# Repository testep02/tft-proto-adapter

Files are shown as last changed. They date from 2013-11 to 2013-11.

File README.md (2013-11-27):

TFT-Proto Adapters
=================================================================================
The files in this repository are schematics and boards for use in Eagle that provide an easy connection for the TFT-Proto from MikroE to the STM32F4 Discovery. There are 3 different variations of the board in this repository. All of these designs have been verified to work. They can easily be printed through OshPark.

Features
---------------------------------------------------------------------------------
-  TFT backlight connected to a pin to allow PWM control
-  Backlight powered from 5V instead of 3.3V to allow for brighter viewing
-  Backlight controlled through a transistor to prevent driving the LEDs directly from a pin
-  Reset pin also routed through a transistor and connected to a pin for software control

Variations
---------------------------------------------------------------------------------
-  16-bit FSMC Portrait
	-  This version of the board mounts the TFT in portrait mode
	-  The connection to the STM32F4 Discovery is 16-bit parallel and uses FSMC.
-  16-Bit FSMC Landscape
	-  Same as the above variation, except with this one the board is laid out so that the screen is in landscape configuration. This is the variatioon I use.
-  16-bit GPIO
	-  Uses entire GPIOE port for data lines
	-  Uses sme pins on the GPIOB port for control
	-  IM[3:0] are connected to header pins to allow configuration between 16-bit and 8-bit
	-  Is not connected to the FSMC pins, so bit-banging is required

Code Examples
---------------------------------------------------------------------------------
Examples of driving the TFT-Proto can be found in my other repository. The drivers include all init code and basic drawing functions.

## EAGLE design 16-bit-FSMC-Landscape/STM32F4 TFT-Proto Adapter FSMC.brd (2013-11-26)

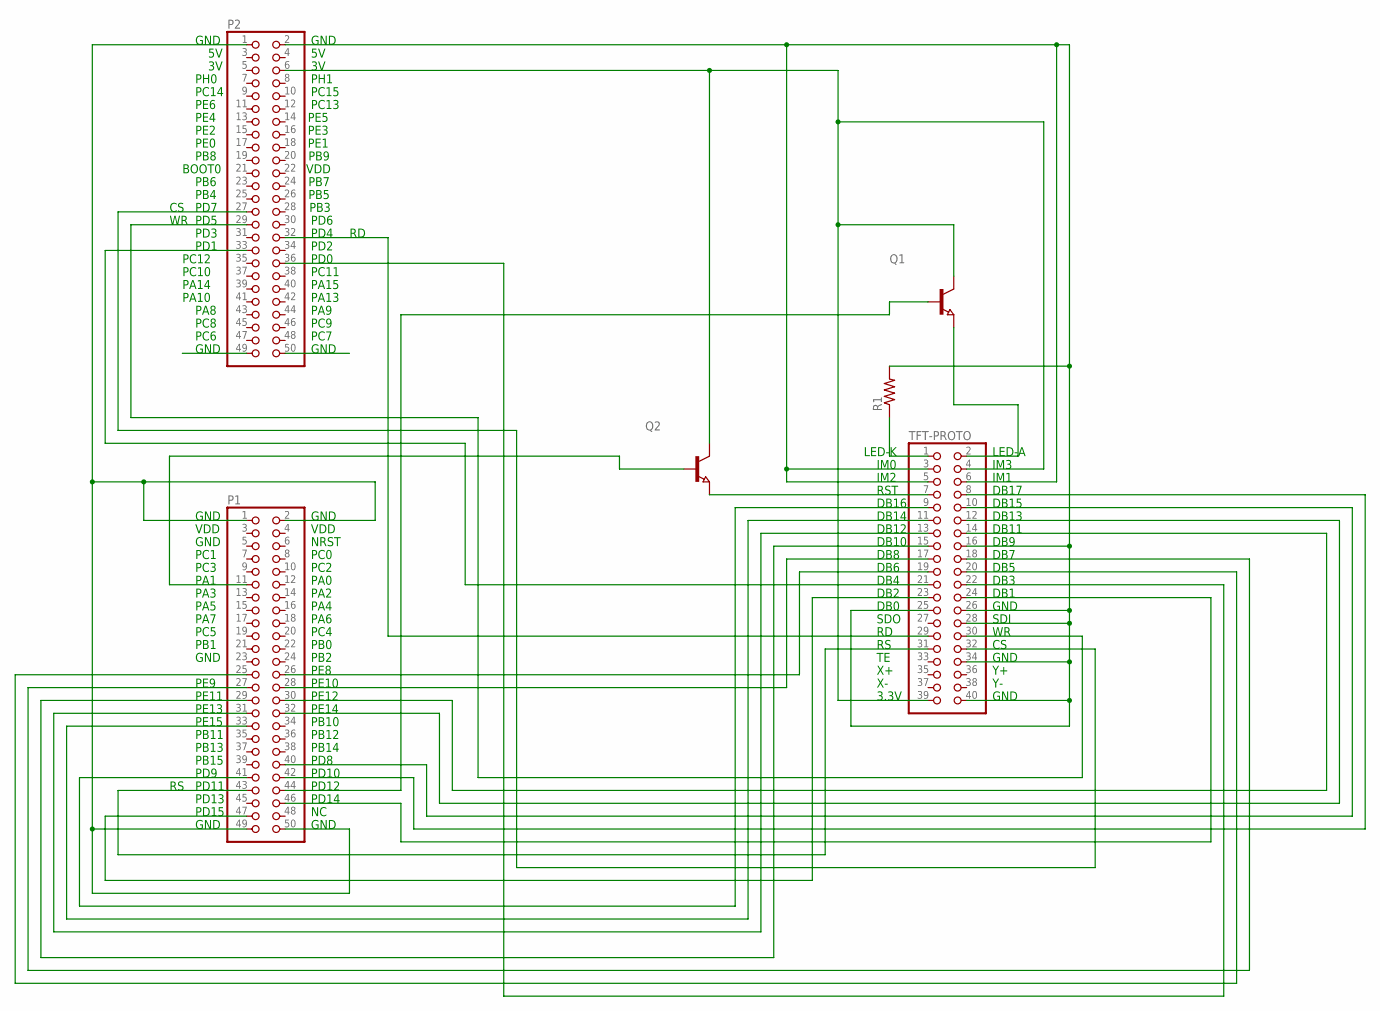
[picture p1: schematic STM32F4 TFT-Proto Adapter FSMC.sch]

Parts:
P1, P2: PINHD-2X25; 2X25
Q1, Q2: NPN-TRANSISTOR_SOT23; SOT23
R1: R-US_R0805; R0805
TFT-PROTO: PINHD-2X20; 2X20

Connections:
CS: P2.27, TFT-PROTO.32
DB1: P1.46, TFT-PROTO.24
DB2: P1.47, TFT-PROTO.23
DB3: P2.36, TFT-PROTO.22
DB4: P2.33, TFT-PROTO.21
DB5: P1.25, TFT-PROTO.20
DB6: P1.26, TFT-PROTO.19
DB7: P1.27, TFT-PROTO.18
DB8: P1.28, TFT-PROTO.17
DB10: P1.29, TFT-PROTO.15
DB11: P1.30, TFT-PROTO.14
DB12: P1.31, TFT-PROTO.13
DB13: P1.32, TFT-PROTO.12
DB14: P1.33, TFT-PROTO.11
DB15: P1.40, TFT-PROTO.10
DB16: P1.41, TFT-PROTO.9
DB17: P1.42, TFT-PROTO.8
GND: P1.1, P1.2, P1.49, P1.50, P2.1, P2.2, P2.49, P2.50, R1.2, TFT-PROTO.3, TFT-PROTO.5, TFT-PROTO.6, TFT-PROTO.16, TFT-PROTO.25, TFT-PROTO.26, TFT-PROTO.28, TFT-PROTO.34, TFT-PROTO.40
unnamed: P1.44, Q1.1 (B)
unnamed: R1.1, TFT-PROTO.1
unnamed: Q1.2 (E), TFT-PROTO.2
unnamed: Q2.2 (E), TFT-PROTO.7
PWR: P2.6, Q1.3 (C), Q2.3 (C), TFT-PROTO.4, TFT-PROTO.39
RD: P2.32, TFT-PROTO.29
RS: P1.43, TFT-PROTO.31
RST: P1.11, Q2.1 (B)
WR: P2.29, TFT-PROTO.30

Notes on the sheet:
GND
PH0
PH1
PC14
PC15
PE6
PC13
PE4 PE5
PE2 PE3
PE0 PE1
PB8 PB9
BOOT0 VDD
PB6 PB7
PB4 PB5
PD7 PB3
PD5
PD3
PD1
PC12
PC10
PA14
PA10
PA8
PC8
PC6
PC7
PC9
PA9
PA13
PA15
PC11
PD0
PD2
PD4
PD6
PD15
PD13
PD11
PD9
PB15

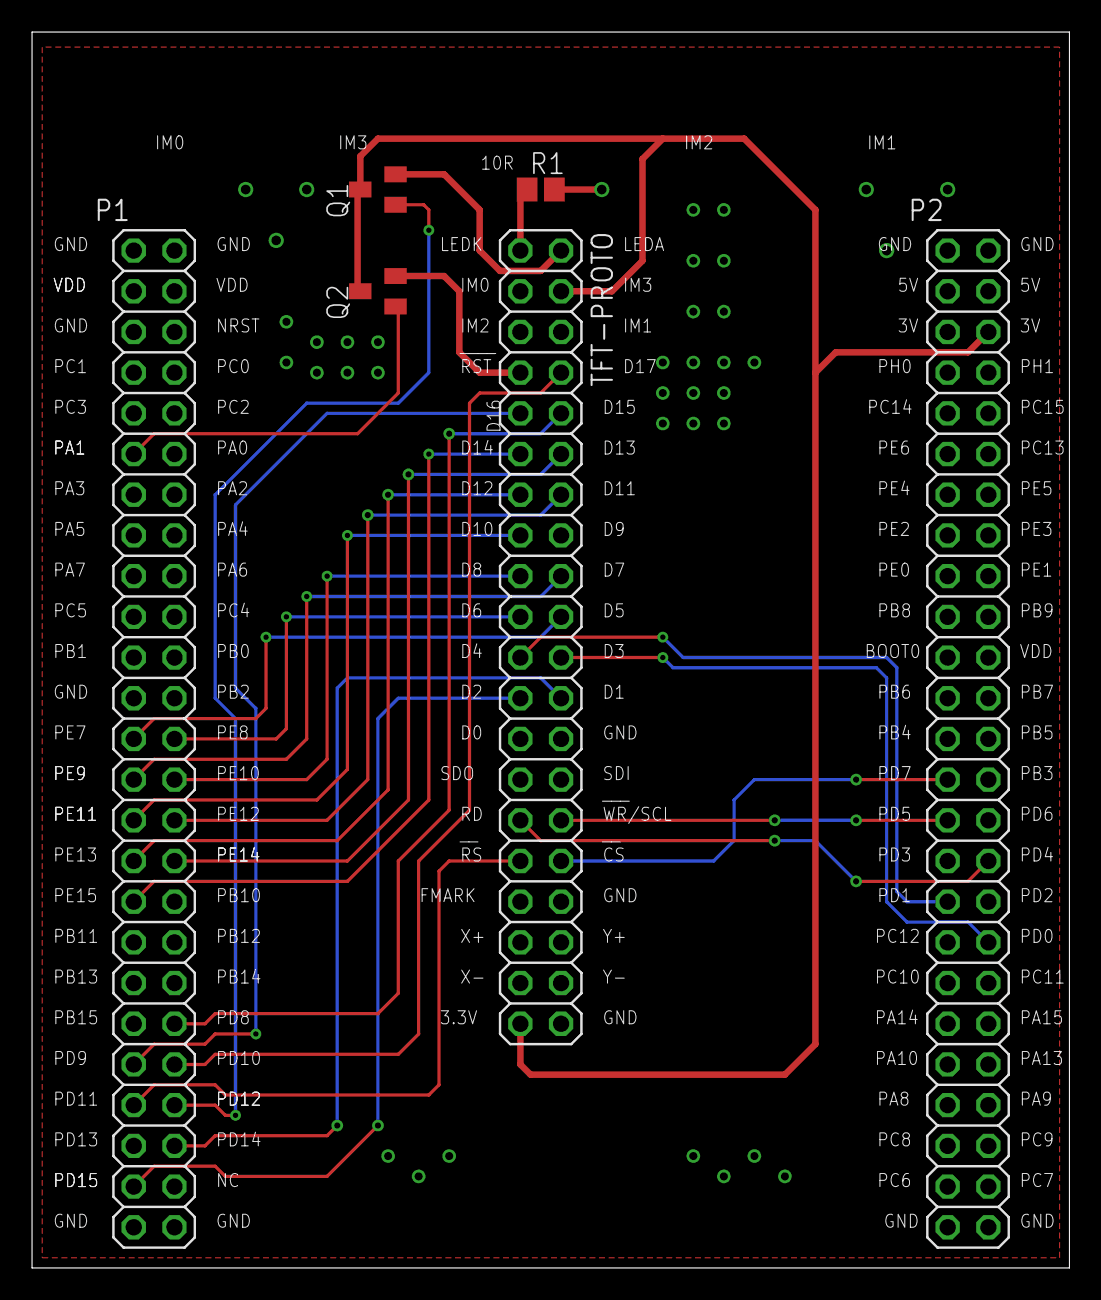
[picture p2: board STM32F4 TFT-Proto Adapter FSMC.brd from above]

Board: 2 copper layers, 64.8 x 77.1 mm, 6 parts (0 on the bottom side), 27 nets.

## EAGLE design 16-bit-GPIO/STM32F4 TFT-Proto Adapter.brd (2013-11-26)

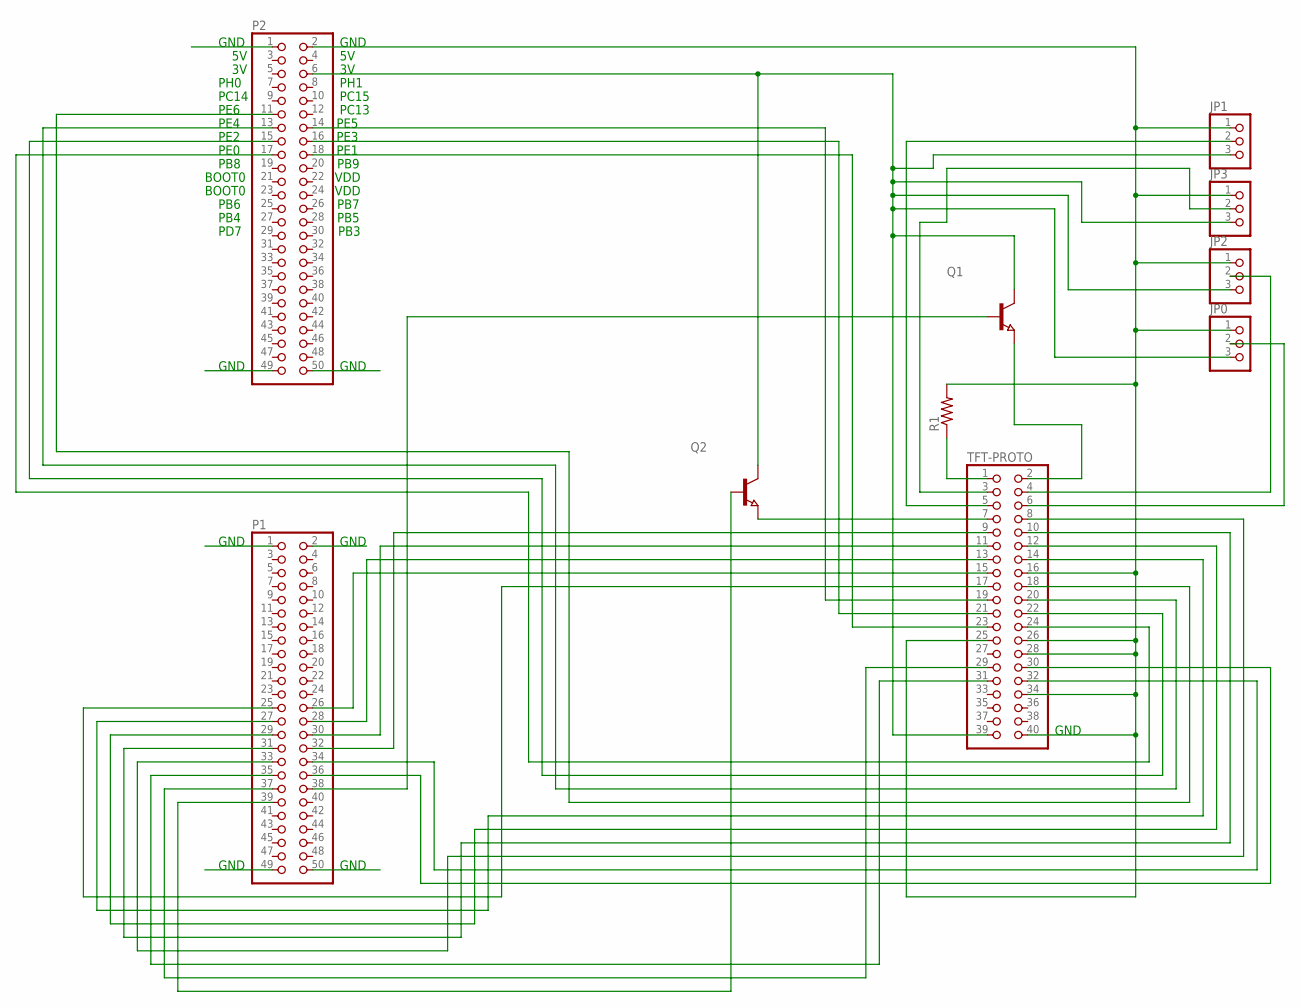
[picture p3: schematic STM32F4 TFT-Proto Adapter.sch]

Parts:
JP0, JP1, JP2, JP3: PINHD-1X3; 1X03
P1, P2: PINHD-2X25; 2X25
Q1, Q2: NPN-TRANSISTOR_SOT23; SOT23
R1: R-US_R0805; R0805
TFT-PROTO: PINHD-2X20; 2X20

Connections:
CS: P1.34, TFT-PROTO.32
DAT1: P2.17, TFT-PROTO.24
DAT2: P2.18, TFT-PROTO.23
DAT3: P2.15, TFT-PROTO.22
DAT4: P2.16, TFT-PROTO.21
DAT5: P2.13, TFT-PROTO.20
DAT6: P2.14, TFT-PROTO.19
DAT7: P2.11, TFT-PROTO.18
DAT8: P1.25, TFT-PROTO.17
DAT10: P1.26, TFT-PROTO.15
DAT11: P1.27, TFT-PROTO.14
DAT12: P1.28, TFT-PROTO.13
DAT13: P1.29, TFT-PROTO.12
DAT14: P1.30, TFT-PROTO.11
DAT15: P1.31, TFT-PROTO.10
DAT16: P1.32, TFT-PROTO.9
DAT17: P1.33, TFT-PROTO.8
GND: JP0.1, JP1.1, JP2.1, JP3.1, P1.1, P1.2, P1.49, P1.50, P2.1, P2.2, P2.49, P2.50, R1.2, TFT-PROTO.16, TFT-PROTO.25, TFT-PROTO.26, TFT-PROTO.28, TFT-PROTO.34, TFT-PROTO.40
IM0: JP3.2, TFT-PROTO.3
IM1: JP0.2, TFT-PROTO.6
IM2: JP1.2, TFT-PROTO.5
IM3: JP2.2, TFT-PROTO.4
LEDA: P1.38, Q1.1 (B)
unnamed: R1.1, TFT-PROTO.1
unnamed: Q1.2 (E), TFT-PROTO.2
unnamed: Q2.2 (E), TFT-PROTO.7
PWR: JP0.3, JP1.3, JP2.3, JP3.3, P2.6, Q1.3 (C), Q2.3 (C), TFT-PROTO.39
RD: P1.37, TFT-PROTO.29
RS: P1.35, TFT-PROTO.31
RST: P1.39, Q2.1 (B)
WR: P1.36, TFT-PROTO.30

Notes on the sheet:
GND
PH0
PH1
PC14
PC15
PE6
PC13
PE4 PE5
PE2 PE3
PE0 PE1
PB8 PB9
BOOT0 VDD
PB6 PB7
PB4 PB5
PD7 PB3

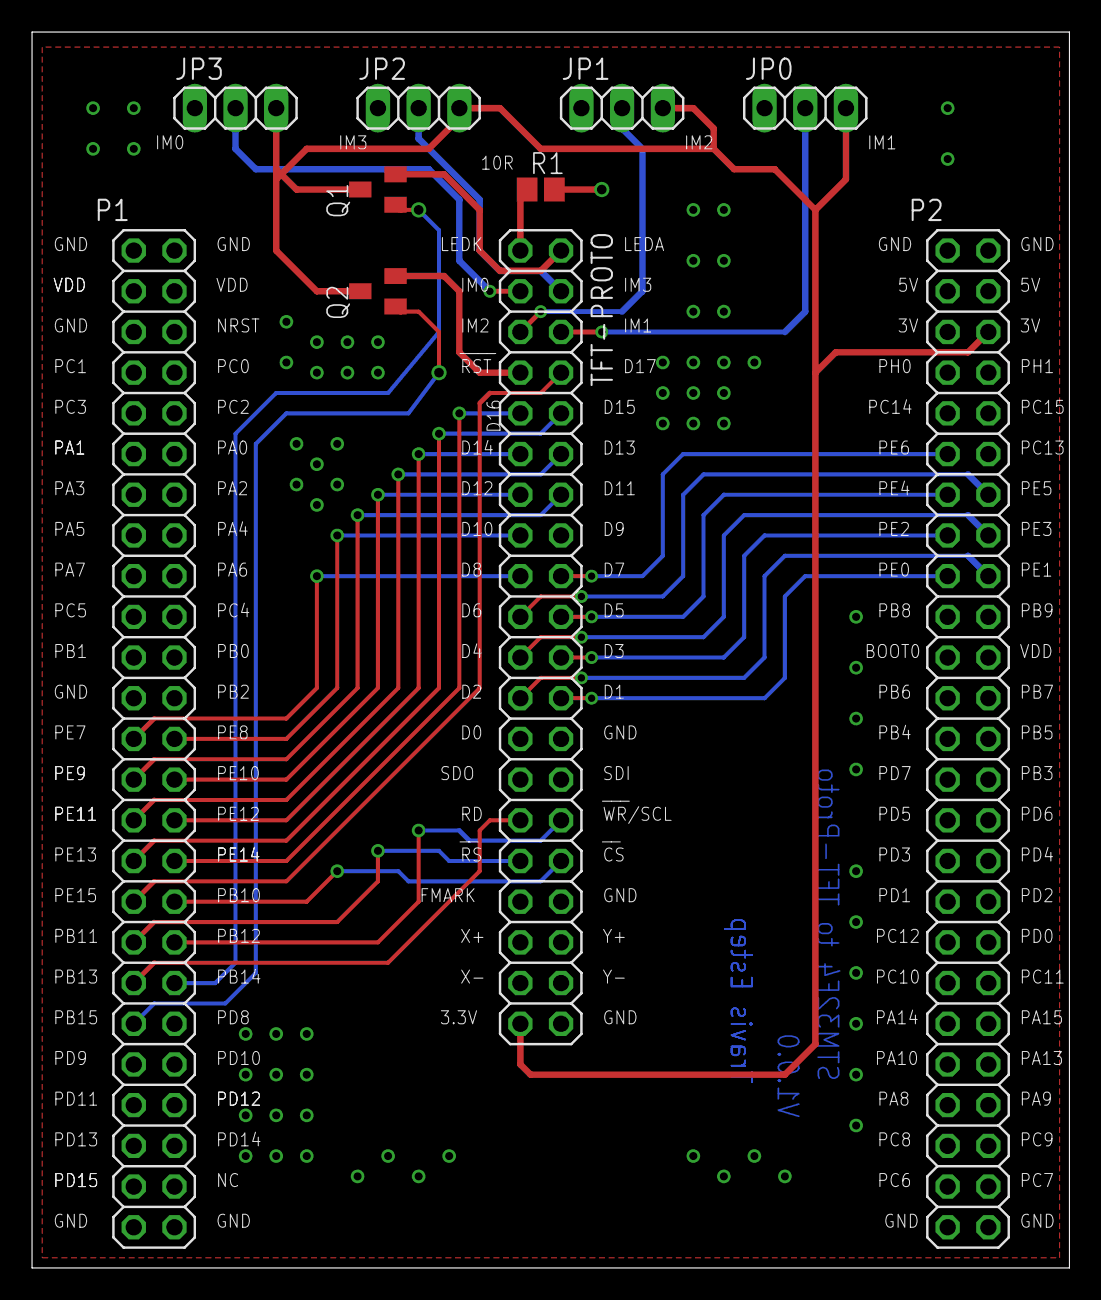
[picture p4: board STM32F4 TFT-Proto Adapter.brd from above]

Board: 2 copper layers, 64.8 x 77.1 mm, 10 parts (0 on the bottom side), 31 nets.
